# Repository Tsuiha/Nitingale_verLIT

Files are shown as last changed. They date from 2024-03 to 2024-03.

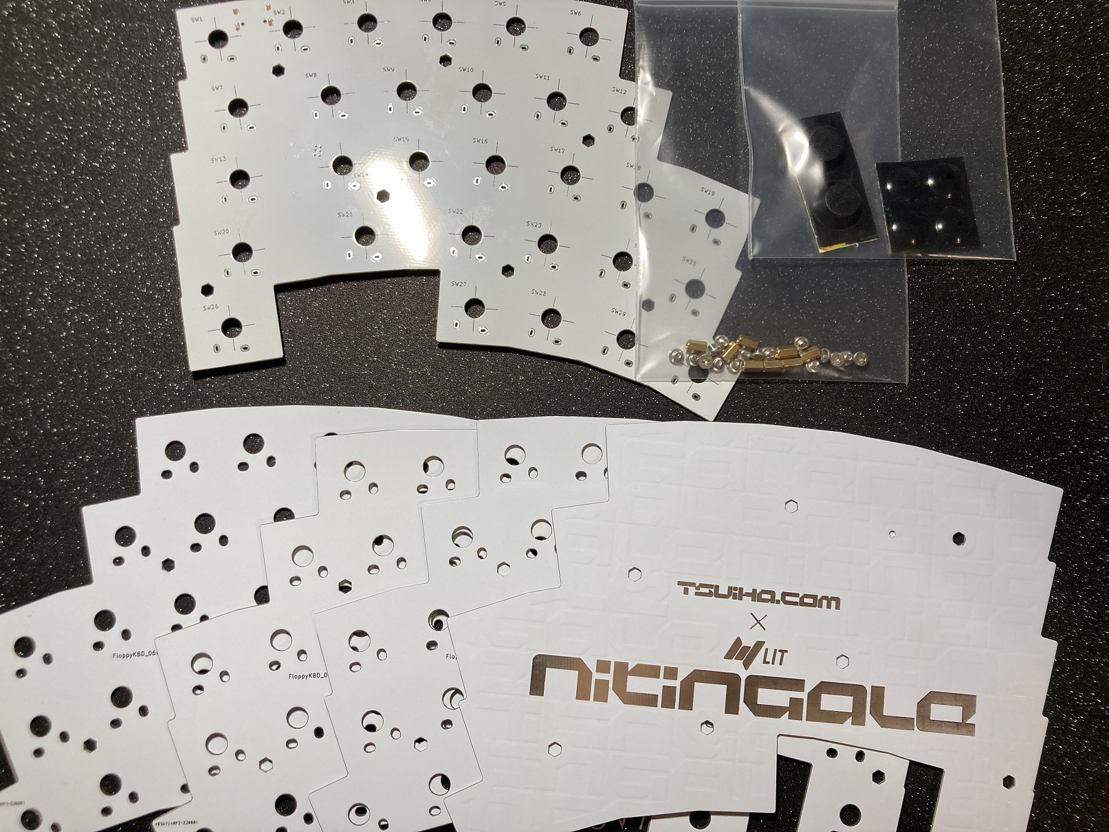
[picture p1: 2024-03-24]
nitingale_image3.JPG

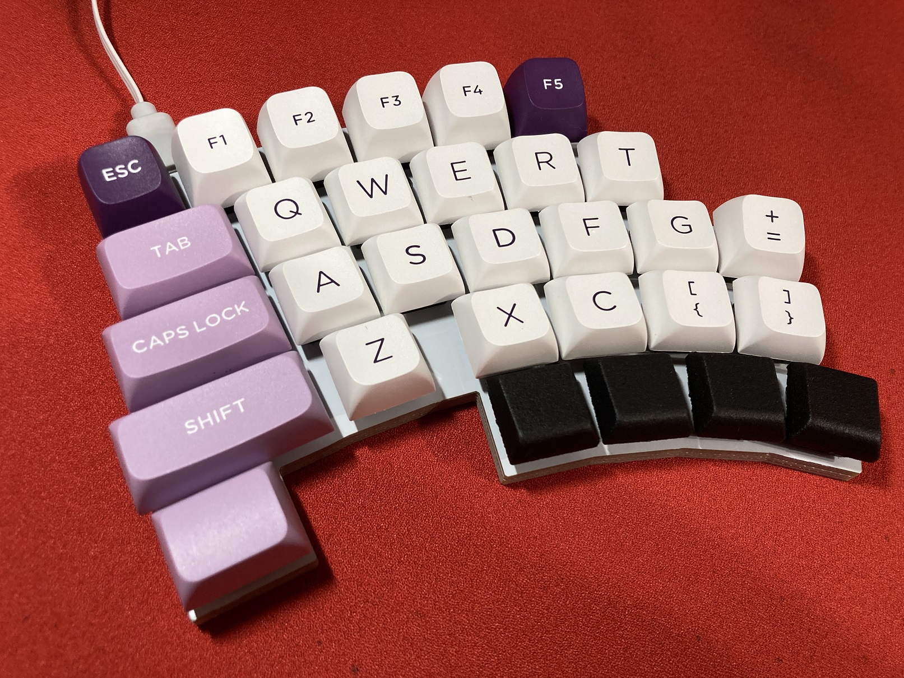
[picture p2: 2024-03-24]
nitingale_image1.JPG

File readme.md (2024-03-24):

Nitingale ver.LIT
30keys left hand keyboard, gaming device, macropad
rp2040 qmk keyboard

Contact
Twitter : @TsuihaJP
E-mail : contact@tsuiha.com

build guide : https://tsuiha.com/nitingale_lit_buildguide/
describe : https://tsuiha.com/nitingale_verlit/

In addition to the pcb, an M2 x 2 mm screw, an M2 x 5 mm spacer and a gateron lowprofile 2.0 switch are required

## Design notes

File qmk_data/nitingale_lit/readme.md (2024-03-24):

# Nitingale
FloppyKBD No.06
Version6:LIT.ver
Name:Nitingale

30keys Left hand device for FPS gaming and macro pad

use gateron low profile 2.0
row staggered and curved array
use rp2040

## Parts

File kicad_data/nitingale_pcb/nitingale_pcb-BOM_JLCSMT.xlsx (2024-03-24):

Comment | Designator | Footprint | JLCPCB Part #（optional）
100nF | C1,C4,C6,C7,C9,C10,C11,C12,C13,C14 | C_0402_1005Metric | C1525
1uF | C2,C8 | C_0402_1005Metric | C52923
10uF | C3,C5,C15 | C_0402_1005Metric | C315248
1kohm | R1,R3 | C_0402_1005Metric | C11702
27ohm | R2,R4 | C_0402_1005Metric | C25100
5.1kohm | R6,R7 | C_0402_1005Metric | C25905
rp2040 | U1 | QFN-56-1EP_7x7mm_P0.4mm_EP3.2x3.2mm | C2040
W25Q128JVPIQ | U2 | WSON-8-1EP_6x5mm_P1.27mm_EP3.4x4.3mm | C190862
NCP1117-1.5_TO252 | U3 | TO-252-2 | C152470
Crystal_GND2 | Y1 | Resonator_SMD_Murata_CSTxExxV-3Pin_3.0x1.1mm | C341520
SW | SW31 | SW_Push_1P1T_NO_Vertical_Wuerth_434133025816 | C92589
HRO_TYPE-C-31-M-12 | J1 | USB_C_Receptacle_HRO_TYPE-C-31-M-12 | C165948
 | F1 | Fuse_0805_2012Metric | C2833485

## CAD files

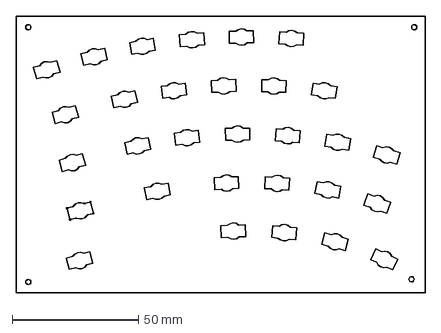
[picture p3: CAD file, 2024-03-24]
dxf_data/Nitingale_jig.dxf
161.7 x 109.3 mm

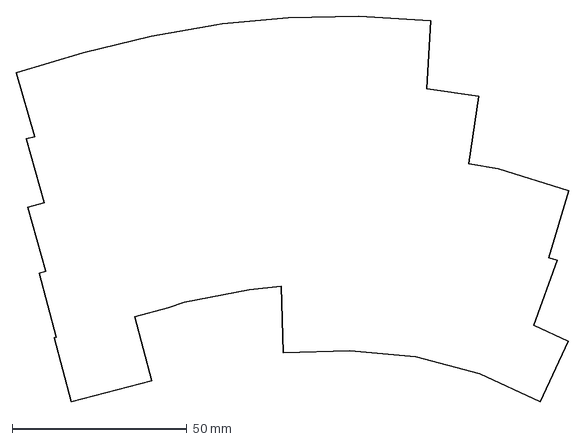
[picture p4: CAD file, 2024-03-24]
dxf_data/Nitingale_outline.dxf
158.1 x 110.4 mm

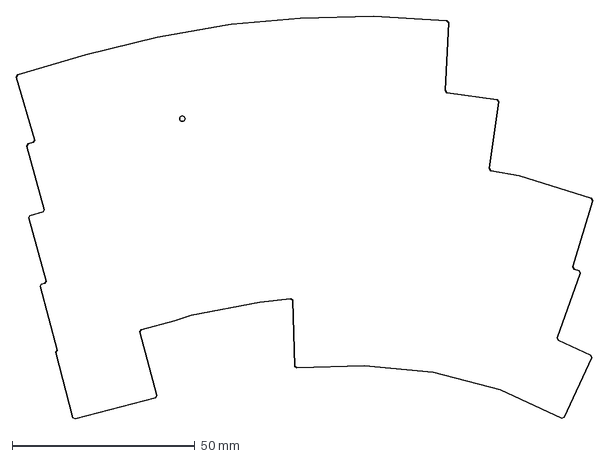
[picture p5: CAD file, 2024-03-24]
dxf_data/Nitingale_botplate.dxf
157.8 x 110.3 mm

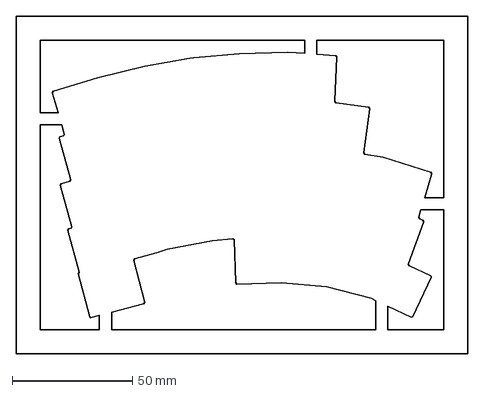
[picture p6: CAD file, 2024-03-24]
dxf_data/Nitingale_pcb.dxf
187.8 x 140.3 mm

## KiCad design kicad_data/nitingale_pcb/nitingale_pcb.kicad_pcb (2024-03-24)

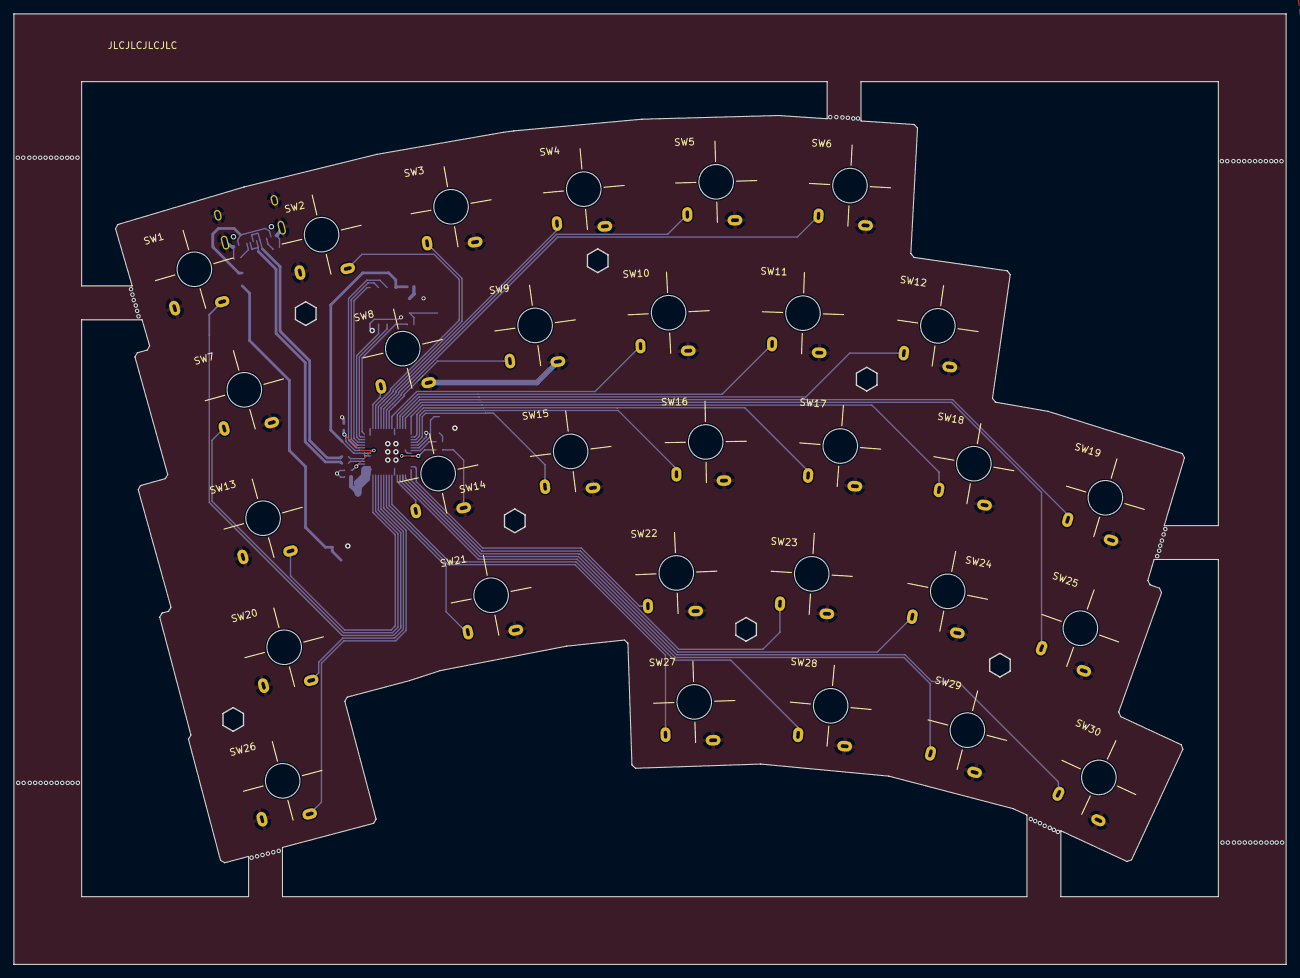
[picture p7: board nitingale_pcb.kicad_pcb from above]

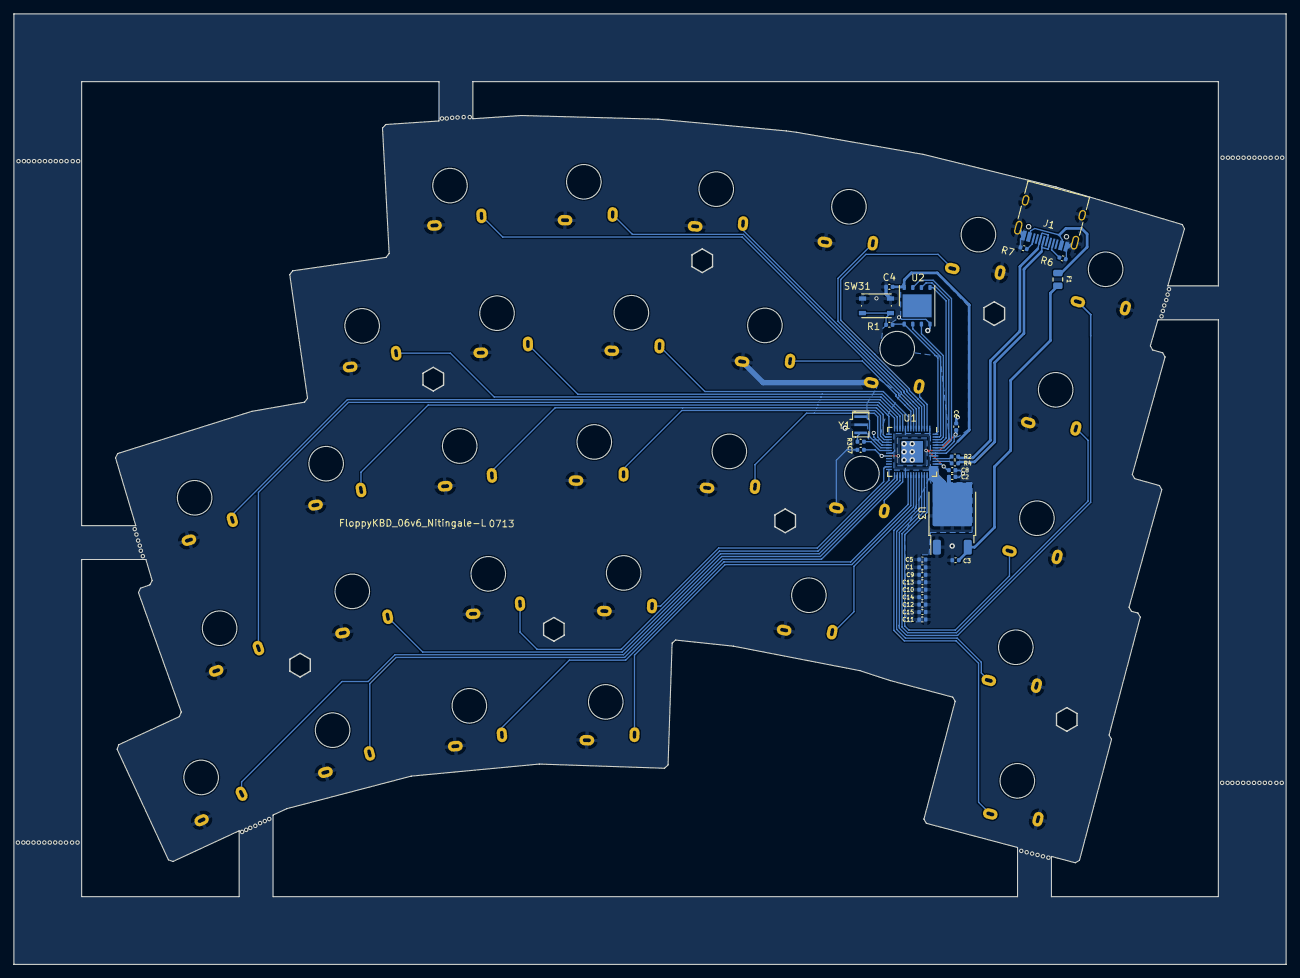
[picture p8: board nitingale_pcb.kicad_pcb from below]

Board: 2 copper layers, 187.8 x 140.3 mm, 58 parts (28 on the bottom side), 51 nets.

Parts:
C1, C4, C6, C7, C9, C10, C11, C12, C13, C14: 100n; C_0402_1005Metric
C2, C8: 1u; C_0402_1005Metric
C3, C5, C15: 10u; C_0402_1005Metric
F1: Polyfuse; Fuse_0805_2012Metric
J1: USB_C_Receptacle; USB_C_Receptacle_HRO_TYPE-C-31-M-12
R1, R3: 1k; C_0402_1005Metric
R2, R4: 27; C_0402_1005Metric
R6, R7: 5.1k; C_0402_1005Metric
SW1, SW2, SW3, SW4, SW5, SW6, SW7, SW8, SW9, SW10, SW11, SW12, SW13, SW14, SW15, SW16, SW17, SW18, SW19, SW20, SW21, SW22, SW23, SW24, SW25, SW26, SW27, SW28, SW29, SW30: SW_PUSH; GLP2-nitingale
SW31: SW_PUSH; SW_Push_1P1T_NO_Vertical_Wuerth_434133025816
U1: RP2040; QFN-56-1EP_7x7mm_P0.4mm_EP3.2x3.2mm
U2: W25Q128JVS; WSON-8-1EP_6x5mm_P1.27mm_EP3.4x4.3mm
U3: NCP1117-1.5_TO252; TO-252-2
Y1: Crystal_GND2; Resonator_SMD_Murata_CSTxExxV-3Pin_3.0x1.1mm

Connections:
+1V1: C6.1, C7.1, C8.1, U1.23 (DVDD), U1.45 (VREG_VOUT), U1.50 (DVDD)
+3V3: C1.1, C2.1, C4.1, C5.1, C9.1, C10.1, C11.1, C12.1, C13.1, C14.1, C15.1, U1.1 (IOVDD), U1.10 (IOVDD), U1.22 (IOVDD), U1.33 (IOVDD), U1.42 (IOVDD), U1.43 (ADC_AVDD), U1.44 (VREG_IN), U1.48 (USB_VDD), U1.49 (IOVDD), U2.8 (VCC), U3.2 (VO)
/QSPI_SCLK: U1.52 (QSPI_SCLK), U2.6 (CLK)
/QSPI_SD0: U1.53 (QSPI_SD0), U2.5 (DI(IO0))
/QSPI_SD1: U1.55 (QSPI_SD1), U2.2 (DO(IO1))
/QSPI_SD2: U1.54 (QSPI_SD2), U2.3 (IO2)
/QSPI_SD3: U1.51 (QSPI_SD3), U2.7 (IO3)
/QSPI_SS: R1.1, U1.56 (QSPI_SS), U2.1 (~CS)
/USB_D+: J1.A6 (D+), J1.B6 (D+), R2.2
/USB_D-: J1.A7 (D-), J1.B7 (D-), R4.2
/XIN: U1.20 (XIN), Y1.1
/XOUT: R3.1, U1.21 (XOUT)
/~USB_BOOT: R1.2, SW31.1
GND: C1.2, C2.2, C3.2, C4.2, C5.2, C6.2, C7.2, C8.2, C9.2, C10.2, C11.2, C12.2, C13.2, C14.2, C15.2, J1.A1 (GND), J1.A12 (GND), J1.B1 (GND), J1.B12 (GND), J1.S1 (SHIELD), R6.1, R7.1, SW1.1, SW2.1, SW3.2, SW4.2, SW5.2, SW6.2, SW7.2, SW8.2, SW9.2, SW10.2, SW11.2, SW12.2, SW13.1, SW14.2, SW15.2, SW16.2, SW17.2, SW18.2, SW19.2, SW20.1, SW21.2, SW22.2, SW23.2, SW24.2, SW25.2, SW26.1, SW27.2, SW28.2, SW29.2, SW30.2, SW31.2, U1.19 (TESTEN), U1.57 (GND), U2.4 (GND), U3.1 (GND), Y1.2
unnamed: J1.A5 (CC1), R6.2
unnamed: J1.B5 (CC2), R7.2
unnamed: R3.2, Y1.3
unnamed: R4.1, U1.46 (USB_DM)
unnamed: R2.1, U1.47 (USB_DP)
unnamed: C3.1, F1.2, U3.3 (VI)
VBUS: F1.1, J1.A4 (VBUS), J1.A9 (VBUS), J1.B4 (VBUS), J1.B9 (VBUS)
sw01: SW1.2, U1.39 (GPIO27_ADC1)
sw02: SW2.2, U1.3 (GPIO1)
sw03: SW3.1, U1.4 (GPIO2)
sw04: SW4.1, U1.5 (GPIO3)
sw05: SW5.1, U1.6 (GPIO4)
sw06: SW6.1, U1.7 (GPIO5)
sw07: SW7.1, U1.40 (GPIO28_ADC2)
sw08: SW8.1, U1.2 (GPIO0)
sw09: SW9.1, U1.8 (GPIO6)
sw10: SW10.1, U1.9 (GPIO7)
sw11: SW11.1, U1.11 (GPIO8)
sw12: SW12.1, U1.12 (GPIO9)
sw13: SW13.2, U1.41 (GPIO29_ADC3)
sw14: SW14.1, U1.32 (GPIO21)
sw15: SW15.1, U1.18 (GPIO15)
sw16: SW16.1, U1.17 (GPIO14)
sw17: SW17.1, U1.16 (GPIO13)
sw18: SW18.1, U1.15 (GPIO12)
sw19: SW19.1, U1.13 (GPIO10)
sw20: SW20.2, U1.38 (GPIO26_ADC0)
sw21: SW21.1, U1.36 (GPIO24)
sw22: SW22.1, U1.27 (GPIO16)
sw23: SW23.1, U1.28 (GPIO17)
sw24: SW24.1, U1.29 (GPIO18)
sw25: SW25.1, U1.14 (GPIO11)
sw26: SW26.2, U1.37 (GPIO25)
sw27: SW27.1, U1.35 (GPIO23)
sw28: SW28.1, U1.34 (GPIO22)
sw29: SW29.1, U1.31 (GPIO20)
sw30: SW30.1, U1.30 (GPIO19)
